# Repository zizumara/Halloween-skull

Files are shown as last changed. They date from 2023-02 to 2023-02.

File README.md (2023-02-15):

# Anamatronic Halloween Skull
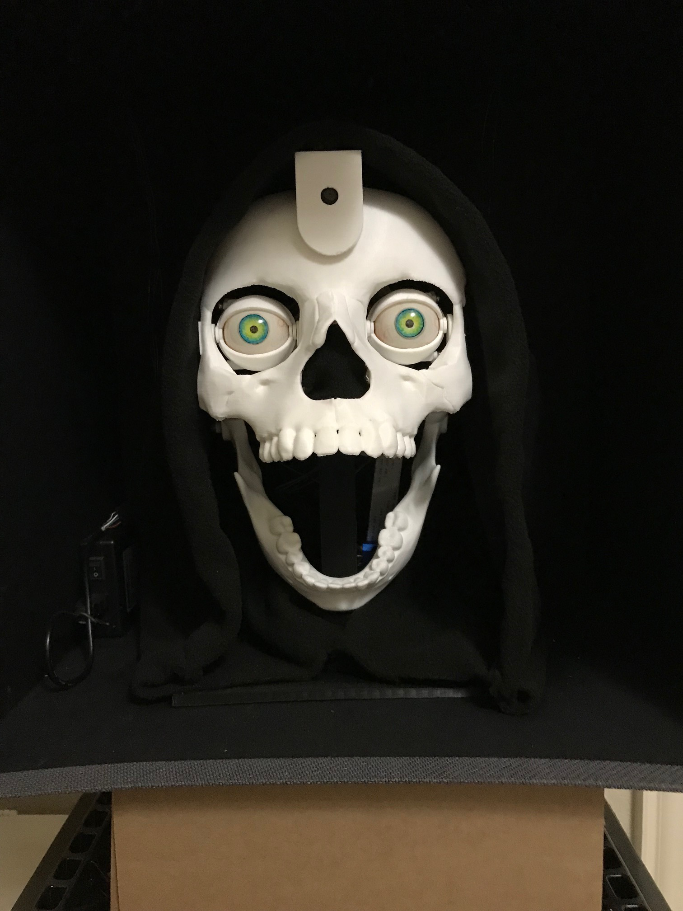
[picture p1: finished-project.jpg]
Finished Project


The eyes in this 3D-printed Halloween project track the movement of faces visible to the Raspberry Pi camera mounted in the forehead.  Eyelid and jaw motions are also controlled with servos to create various expressions (asleep, surprised, talking, etc.) based on the proximity of the person's face.  A small speaker set is attached to the Raspberry Pi to play audio files to go with the expressions.  This is the second of two designs.  In this design, the eyes can be moved independently of each other, whereas the left and right eyelids are limited to moving together.

The eyes are based on this Nilheim Mechatronics project:
http://www.nilheim.co.uk/latest-projects-and-blog/simplified-3d-printed-animatronic-dual-eye-mechanism

The 3D printed skull face was adapted from this Thingiverse project:
https://www.thingiverse.com/thing:4830026

Face detection with Open CV is based on this PyImageSearch tutorial:
https://pyimagesearch.com/2018/02/26/face-detection-with-opencv-and-deep-learning/

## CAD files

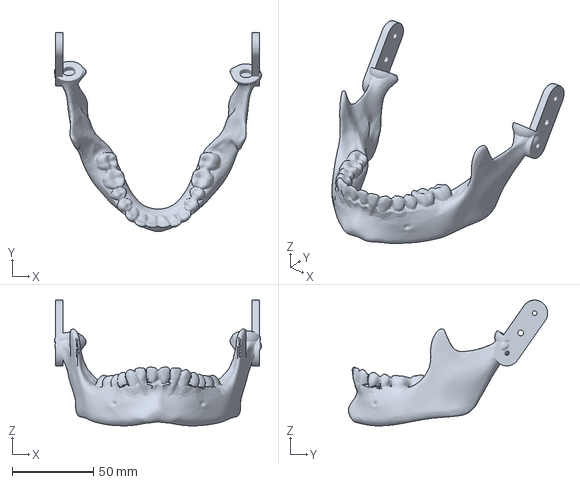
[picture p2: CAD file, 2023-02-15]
3D-printer-files/Mech_Eyes_Mandible.3mf
127.7 x 122.9 x 77.7 mm

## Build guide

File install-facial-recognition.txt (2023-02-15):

1. Update Pi O/S (Buster).
sudo apt-get update
sudo apt-get dist-upgrade

2. Use raspi-config Advanced menu to expand file system and reboot.

3. Install dependencies.
sudo apt-get install build-essential cmake pkg-config
sudo apt-get install libjpeg-dev libtiff5-dev libjasper-dev libpng-dev
sudo apt-get install libavcodec-dev libavformat-dev libswscale-dev libv4l-dev
sudo apt-get install libxvidcore-dev libx264-dev
sudo apt-get install libfontconfig1-dev libcairo2-dev
sudo apt-get install libgdk-pixbuf2.0-dev libpango1.0-dev
sudo apt-get install libgtk2.0-dev libgtk-3-dev
sudo apt-get install libatlas-base-dev gfortran
sudo apt-get install libhdf5-dev libhdf5-serial-dev libhdf5-103
sudo apt-get install libqtgui4 libqtwebkit4 libqt4-test python3-pyqt5
sudo apt-get install python3-dev

4. Create Python virtual environment and install NumPy.
wget https://bootstrap.pypa.io/get-pip.py
sudo python3 get-pip.py
sudo rm -rf ~/.cache/pip
sudo pip install virtualenv virtualenvwrapper
nano ~/.bashrc
Add the following to the end of .bashrc:
  export WORKON_HOME=$HOME/.virtualenvs
  export VIRTUALENVWRAPPER_PYTHON=/usr/bin/python3
  source /usr/local/bin/virtualenvwrapper.sh
Save with CTL-O, ENTER. and then exit with CTL-X.
source ~/.bashrc
mkvirtualenv cv -p python3 --system-site-packages
pip install "picamera[array]"

5. Compile OpenCV from source.
cd ~
wget -O opencv.zip https://github.com/opencv/opencv/archive/4.1.1.zip
wget -O opencv_contrib.zip https://github.com/opencv/opencv_contrib/archive/4.1.1.zip
unzip opencv.zip
unzip opencv_contrib.zip
mv opencv-4.1.1 opencv
mv opencv_contrib-4.1.1 opencv_contrib
sudo nano /etc/dphys-swapfile
Change CONF_SWAPSIZE=100 to CONF_SWAPSIZE=2048.
Save with CTL-O, ENTER. and then exit with CTL-X.
sudo /etc/init.d/dphys-swapfile stop
sudo /etc/init.d/dphys-swapfile start
workon cv
pip install numpy
cd ~/opencv
mkdir build
cd build
cmake -D CMAKE_BUILD_TYPE=RELEASE \
-D CMAKE_INSTALL_PREFIX=/usr/local \
-D OPENCV_EXTRA_MODULES_PATH=~/opencv_contrib/modules \
-D ENABLE_NEON=ON \
-D ENABLE_VFPV3=ON \
-D BUILD_TESTS=OFF \
-D INSTALL_PYTHON_EXAMPLES=OFF \
-D OPENCV_ENABLE_NONFREE=ON \
-D CMAKE_SHARED_LINKER_FLAGS=-latomic \
-D BUILD_EXAMPLES=OFF ..
The following command will compile OpenCV from source.  It may take hours to complete:
make -j4

6. Install OpenCV.
sudo make install
sudo ldconfig

7. Restore swap file size.
sudo nano /etc/dphys-swapfile
Change CONF_SWAPSIZE=2048 to CONF_SWAPSIZE=100.
Save with CTL-O, ENTER. and then exit with CTL-X.
sudo /etc/init.d/dphys-swapfile stop
sudo /etc/init.d/dphys-swapfile start

8. Add sym links to OpenCV (use appropriate latest python3 version; check paths).
cd /usr/local/lib/python3.7/site-packages/cv2/python-3.7
sudo mv cv2.cpython-37m-arm-linux-gnueabihf.so cv2.so
cd ~/.virtualenvs/cv/lib/python3.7/site-packages/
ln -s /usr/local/lib/python3.7/site-packages/cv2/python-3.7/cv2.so cv2.so

9. Test OpenCV installation.
cd ~
workon cv
python
>>> import cv2
>>> cv2.__version__
'4.1.1'
>>>
(use CTL-D to exit python)

10. Install required Python modules.
pip install numpy scipy imutils

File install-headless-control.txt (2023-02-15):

Installation Instructions for Running Headless
(see https://github.com/zizumara/RunHeadless for headless control panel design)

These instructions assume that runheadless.py is located in /home/pi/face-tracker

1. Copy face-tracker.sh to directory /usr/local/bin.

2. Make sure face-tracker.sh is executable with

      sudo chmod 755 /usr/local/bin/face-tracker.sh

3. Copy face-tracker.service to directory /lib/systemd/system.

4. Use the following to enable the service on startup.

      sudo systemctl enable face-tracker

5. To check status after startup, use

      sudo systemctl status face-tracker

6. To stop the service, use

      sudo systemctl stop face-tracker

7. To restart the service, use

      sudo systemctl start face-tracker

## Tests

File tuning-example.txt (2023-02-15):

To perform tuning, run face-tracker.py with -i and -b options to display
video on the desktop and to draw a bounding box around detected faces:
   python3 face-tracker.py -i -b

Note that the following lines in face-tracker.py must be uncommented in order 
to print the bounding box center coordinates on the console.
#            print(f'face at {ratioH:.3f},{ratioV:.3f} '
#                  f'(HL {horizPosL:.1f} VL {vertPosL:.1f} '
#                  f'HR {horizPosR:.1f} VR {vertPosR:.1f} '
#                  f'{mode}); {detectTime:.4f} sec; area {boxArea}')

In a 400x300 pixel frame, the limits of the bounding box centroid are approximately as follows:
   x=35 to 370
   y=35 to 265

This makes the relative position (0.0 - 1.0) of the centroid coordinates (x,y) in the frame to be:
   horiz = (x - 35) / (370 - 35) = (x - 35) / 335
   vert  = 1.0 - (y - 35) / (265 - 35) = 1.0 - (y - 35) / 230
(Note: The vertical ratio flips the y-axis so that 0.0 is at the bottom of the frame.)
(Note: Because the limits are approximations, the values should be cropped to the range 0.0 to 1.0.)

By aligning the eyes to point at the face at each bounding box limit, the limits of the servo
angles are established approximately as follows:
   Left Eye
   channel 2 left: 114 (LL) to 129 (UL) degrees (avg 121)
   channel 2 right: 83 (LR) to 93 (UR) degrees (avg 88)
   channel 0 top: 114 (UL) to 114 (UR) degrees (avg 114)
   channel 0 bottom: 85 (LL) to 91 (LR) degrees (avg 88)
   Right Eye
   channel 6 left: 90 (LL) to 90 (UL) degrees (avg 90)
   channel 6 right: 57 (LR) to 66 (UR) degrees (avg 61)
   channel 4 top: 73 (UL) to 73 (UR) degrees (avg 73)
   channel 4 bottom: 94 (LL) to 97 (LR) degrees (avg 95)
(Note: Left and right are from the perspective of the eyes looking outward.)

The formula for converting centroid coordinates to servo angles is thus:
   channel 0 = 88 + vert * (114 - 88)
   channel 2 = 88 + horiz * (121 - 88)
   channel 4 = 95 - vert * (95 - 73)
   channel 6 = 61 + horiz * (90 - 61)
(Note: The right eye vertical servo moves in the opposite direction as the left eye
vertical servo.)

Set initial servo channel minimum and maximum angles according to the average values,
then tweak the values by moving the face around to see if servo settings correspond to
top, right, left, and bottom limits.

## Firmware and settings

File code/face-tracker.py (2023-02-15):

# face-tracker.py
#
# Track a face in a video stream and output servo controls to point
# a pair of anamatronic eyes at the face.  The eye hardware allows
# each eye to move independently, while the upper lids move in
# unison and the lower lids move in unison.
#
# Controls:
#   l - enter left eye adjustment mode, enabling numeric keypad control
#   r - enter right eye adjustment mode, enabling numeric keypad control
#   t - enter tracking mode, enabling automatic face tracking by both eyes
#   q - quit program and show final tracking positions
#   keypad 1 - capture lower left face detection servo position
#   keypad 3 - capture lower right face detection servo position
#   keypad 7 - capture upper left face detection servo position
#   keypad 9 - capture upper right face detection servo position
#   keypad 2 (down arrow) - adjust eyes down
#   keypad 4 (left arrow) - adjust eyes left
#   keypad 6 (right arrow) - adjust eyes right
#   keypad 8 (up arrow) - adjust eyes up
#

from os import _exit, system, getcwd, path, remove
import addpaths
import pca9685
from imutils.video import VideoStream
import numpy as np
import imutils
import math
import time
import cv2
import subprocess
import argparse
import RPi.GPIO as GPIO

#####################################################################
# CONFIGURATION PARAMETERS
#####################################################################

servoCfgFile = 'servo.conf'
modelFile = 'res10_300x300_ssd_iter_140000.caffemodel'
prototxtFile = 'deploy.prototxt'
screamFile = 'scream1.wav'
laughFile = 'laugh.wav'
biteFile = 'bite.wav'
watchingFile = 'watching.wav'
exitFile = 'exitflag'
CONF_THRESH = 0.5           # confidence threshold for face detection
SERVO_FREQ_HZ = 50
CONTROL_I2C_ADDR = 0x40
MAX_NO_ACTIVITY_TIME = 10

#####################################################################
# GLOBAL CONSTANTS
#####################################################################

# Key assignments (returned by cv2.waitKey)
KEY_LOWER_L  = 177  # keypad 1
KEY_DOWN     = 178  # keypad 2
KEY_LOWER_R  = 179  # keypad 3
KEY_LEFT     = 180  # keypad 4
KEY_CENTER   = 181  # keypad 5
KEY_RIGHT    = 182  # keypad 6
KEY_UPPER_L  = 183  # keypad 7
KEY_UP       = 184  # keypad 8
KEY_UPPER_R  = 185  # keypad 9
KEY_ADJUST   = ord('a')
KEY_ADJUST_R = ord('r')
KEY_ADJUST_L = ord('l')
KEY_TRACK    = ord('t')
KEY_QUIT     = ord('q')

# These are the measured limits of the bounding box centroids and the corresponding
# number of pixels between the limits.
BB_MIN_X = 35
BB_MAX_X = 370
BB_MIN_Y = 35
BB_MAX_Y = 265

BB_WIDTH_X = BB_MAX_X - BB_MIN_X   # width in pixels of area where face can be found
BB_HEIGHT_Y = BB_MAX_Y - BB_MIN_Y  # height in pixels of area where face can be found
BB_AREA_RELAXED = 6000             # size of bounding box to trigger relaxed behavior
BB_AREA_STARTLED = 32000           # size of bounding box to trigger startled behavior


#####################################################################
# CLASSES
#####################################################################

class EyeControl():
    """
    This class abstracts the controller setting of eye positions to be relative
    to the configured range of horizontal and vertical angles of the servos.
    """

    MOVE_UP    = 1
    MOVE_DOWN  = 2
    MOVE_LEFT  = 3
    MOVE_RIGHT = 4

    def __init__(self, controller, leftOrRight):
        self.controller = controller
        self.leftOrRight = leftOrRight
        self.chanH = None
        self.chanV = None
        self.chanAngleH = pca9685.ANGLE_INVALID
        self.chanAngleV = pca9685.ANGLE_INVALID
        self.minAngleH = None
        self.maxAngleH = None
        self.minAngleV = None
        self.maxAngleV = None
        self.degreesH = None
        self.degreesV = None
        # Dictionary of recorded face position locations.
        self.locsDict = { KEY_LOWER_L : (0.0, 0.0),
                          KEY_LOWER_R : (0.0, 0.0),
                          KEY_UPPER_L : (0.0, 0.0),
                          KEY_UPPER_R : (0.0, 0.0),
                        }
        # Marked location key names
        self.recordDict = { KEY_LOWER_L : 'lower L',
                            KEY_LOWER_R : 'lower R',
                            KEY_UPPER_L : 'upper L',
                            KEY_UPPER_R : 'upper R'
                           }



    def setConfig(self):
        """
        Set the channel numbers and angle limits for the eyeball servos from their
        configuration names.
        """
        isValid = False
        if self.leftOrRight == 'left':
            self.chanH = self.controller.getChannel('left-x-axis')
            self.chanV = self.controller.getChannel('left-y-axis')
            (self.minAngleH, self.maxAngleH) = self.controller.getLimits('left-x-axis')
            (self.minAngleV, self.maxAngleV) = self.controller.getLimits('left-y-axis')
        else:
            self.chanH = self.controller.getChannel('right-x-axis')
            self.chanV = self.controller.getChannel('right-y-axis')
            (self.minAngleH, self.maxAngleH) = self.controller.getLimits('right-x-axis')
            (self.minAngleV, self.maxAngleV) = self.controller.getLimits('right-y-axis')
        if (not self.chanH == None and not self.chanV == None and
            not self.minAngleH == None and not self.maxAngleH == None and
            not self.minAngleV == None and not self.maxAngleV == None):
            self.degreesH = self.maxAngleH - self.minAngleH
            self.degreesV = self.maxAngleV - self.minAngleV
            isValid = True
        print(f'{self.leftOrRight} eye servo configuration:')
        print(f'  x-axis chan={self.chanH}, min angle={self.minAngleH}, max angle={self.maxAngleH}')
        print(f'  y-axis chan={self.chanV}, min angle={self.minAngleV}, max angle={self.maxAngleV}')
        return isValid

    def center(self):
        """
        Center the eye horizontally and vertically.
        """
        self.chanAngleH = self.controller.setServoPosition(self.chanH, 'center')
        self.chanAngleV = self.controller.setServoPosition(self.chanV, 'center')

    def adjust(self, direction, change):
        """
        Apply a change in degrees to the horizontal or vertical position of the eyeball.
        """
        angleNewH = pca9685.ANGLE_INVALID
        angleNewV = pca9685.ANGLE_INVALID
        if direction == EyeControl.MOVE_UP:
            if self.leftOrRight == 'right':
                change = -change
            angleNewV = self.controller.setServoAngle(self.chanV, self.chanAngleV + change)
        elif direction == EyeControl.MOVE_DOWN:
            if self.leftOrRight == 'right':
                change = -change
            angleNewV = self.controller.setServoAngle(self.chanV, self.chanAngleV - change)
        elif direction == EyeControl.MOVE_LEFT:
            angleNewH = self.controller.setServoAngle(self.chanH, self.chanAngleH + change)
        elif direction == EyeControl.MOVE_RIGHT:
            angleNewH = self.controller.setServoAngle(self.chanH, self.chanAngleH - change)
        if not angleNewH == pca9685.ANGLE_INVALID:
            self.chanAngleH = angleNewH
        if not angleNewV == pca9685.ANGLE_INVALID:
            self.chanAngleV = angleNewV

    def setRelativePosition(self, ratioHoriz, ratioVert):
        """
        Set the relative horizontal (0 - 1.0) and vertical (0 - 1.0) position of
        the eyeball, where a horizontal ratio of 1.0 is all the way to the left and
        a vertical ratio of 1.0 is all the way up.
        """
        angleNewH = self.minAngleH + (ratioHoriz * self.degreesH)
        if self.leftOrRight == 'left':
            angleNewV = self.minAngleV + (ratioVert * self.degreesV)
        else:
            angleNewV = self.maxAngleV - (ratioVert * self.degreesV)
        angleNewH = self.controller.setServoAngle(self.chanH, angleNewH)
        angleNewV = self.controller.setServoAngle(self.chanV, angleNewV)
        if not angleNewH == pca9685.ANGLE_INVALID:
            self.chanAngleH = angleNewH
        if not angleNewV == pca9685.ANGLE_INVALID:
            self.chanAngleV = angleNewV

    def getCurrentPosition(self):
        """
        Return current horizontal and vertical eyeball servo positions in degrees.
        """
        return (self.chanAngleH, self.chanAngleV)

    def markLocation(self, cmdKey):
        self.locsDict[cmdKey] = (self.chanAngleH, self.chanAngleV)
        print(f'Captured {self.recordDict[cmdKey]} position at {self.locsDict[cmdKey]}.')


class ExpressionControl():
    """
    This class abstracts the controller setting of eyelid positions, jaw position, and
    audio effects as behaviors.
    """

    ASLEEP = 1
    RELAXED = 2
    STARTLED = 3
    SUSPICIOUS = 4
    LAUGHING = 5
    WIDEEYED = 6
    BITING = 7

    def __init__(self, controller):
        self.controller = controller
        self.chLidUpper = None
        self.chLidLower = None
        self.chJaw = None
        self.current = None

    def get(self):
        return self.current

    def config(self):
        """
        Set the channel numbers for each servo from their configuration names.
        """
        self.chLidUpper = self.controller.getChannel('upper-lids')
        self.chLidLower = self.controller.getChannel('lower-lids')
        self.chJaw       = self.controller.getChannel('jaw')
        isValid = (not self.chLidUpper == None and
                   not self.chLidLower == None
                   and not self.chJaw == None)
        print('Configure channels:')
        print(f'  upper-lids={self.chLidUpper}')
        print(f'  lower-lids={self.chLidLower}')
        print(f'  jaw={self.chJaw}')
        return isValid

    def setAsleep(self):
        self.current = ExpressionControl.ASLEEP
        self.controller.setServoPosition(self.chLidUpper, 'closed')
        self.controller.setServoPosition(self.chLidLower, 'closed')
        self.controller.setServoPosition(self.chJaw, 'closed')

    def setRelaxed(self):
        self.current = ExpressionControl.RELAXED
        self.controller.setServoPosition(self.chLidUpper, 'halfopen')
        self.controller.setServoPosition(self.chLidLower, 'halfopen')
        self.controller.setServoPosition(self.chJaw, 'closed')

    def setWideEyed(self):
        self.current = ExpressionControl.WIDEEYED
        self.controller.setServoPosition(self.chLidUpper, 'open')
        self.controller.setServoPosition(self.chLidLower, 'open')
        self.controller.setServoPosition(self.chJaw, 'closed')

    def setStartled(self, soundFile):
        self.current = ExpressionControl.STARTLED
        soundProc = subprocess.Popen(['aplay', '-Dhw:0,0', soundFile])
        returnCode = soundProc.poll()
        if returnCode != None:
            print(f'ERROR: Launch of aplay failed with return code {returnCode}.')
        self.controller.setServoPosition(self.chLidUpper, 'open')
        self.controller.setServoPosition(self.chLidLower, 'open')
        self.controller.setServoPosition(self.chJaw, 'open')

    def setSuspicious(self, fraction):
        self.current = ExpressionControl.SUSPICIOUS
        self.controller.setServoPositionRel(self.chLidUpper, 'halfopen', 'closed', fraction)
        self.controller.setServoPositionRel(self.chLidLower, 'halfopen', 'closed', fraction)
        self.controller.setServoPosition(self.chJaw, 'closed')

    def setLaughing(self, soundFile):
        self.current = ExpressionControl.LAUGHING
        soundProc = subprocess.Popen(['aplay', '-Dhw:0,0', soundFile])
        returnCode = soundProc.poll()
        if returnCode != None:
            print(f'ERROR: Launch of aplay failed with return code {returnCode}.')
        for i in range(0,6):
            self.controller.setServoPositionRel(self.chJaw, 'closed', 'open', 0.2)
            time.sleep(0.1)
            self.controller.setServoPosition(self.chJaw, 'closed')
            time.sleep(0.1)

    def setWatching(self, soundFile):
        self.current = ExpressionControl.LAUGHING
        soundProc = subprocess.Popen(['aplay', '-Dhw:0,0', soundFile])
        returnCode = soundProc.poll()
        if returnCode != None:
            print(f'ERROR: Launch of aplay failed with return code {returnCode}.')
        self.controller.setServoPosition(self.chLidUpper, 'open')
        self.controller.setServoPosition(self.chLidLower, 'open')
        # we're
        self.controller.setServoPositionRel(self.chJaw, 'closed', 'open', 0.3)
        time.sleep(0.8)
        self.controller.setServoPosition(self.chJaw, 'closed')
        time.sleep(0.15)
        # watch-
        self.controller.setServoPositionRel(self.chJaw, 'closed', 'open', 0.5)
        time.sleep(0.2)
        self.controller.setServoPosition(self.chJaw, 'closed')
        time.sleep(0.1)
        # -ing
        self.controller.setServoPositionRel(self.chJaw, 'closed', 'open', 0.3)
        time.sleep(0.2)
        self.controller.setServoPosition(self.chJaw, 'closed')
        time.sleep(0.1)
        # you
        self.controller.setServoPositionRel(self.chJaw, 'closed', 'open', 0.5)
        time.sleep(0.8)
        self.controller.setServoPosition(self.chJaw, 'closed')
        time.sleep(0.1)

    def setBiting(self, soundFile):
        self.current = ExpressionControl.BITING
        soundProc = subprocess.Popen(['aplay', '-Dhw:0,0', soundFile])
        returnCode = soundProc.poll()
        if returnCode != None:
            print(f'ERROR: Launch of aplay failed with return code {returnCode}.')
        self.controller.setServoPosition(self.chLidUpper, 'open')
        self.controller.setServoPosition(self.chLidLower, 'open')
        self.controller.setServoPositionRel(self.chJaw, 'closed', 'open', 0.4)
        time.sleep(0.1)
        self.controller.setServoPosition(self.chJaw, 'closed')
        time.sleep(0.1)


class Lighting():
    """
    This class encapsulates the GPIO outputs used to turn lighting on and off.
    """

    PIN_LIGHT1 = 13
    PIN_LIGHT2 = 15
    PIN_LIGHT3 = 16

    def __init__(self):
        GPIO.setmode(GPIO.BOARD)
        GPIO.setwarnings(False)
        GPIO.setup(Lighting.PIN_LIGHT1, GPIO.OUT)
        GPIO.setup(Lighting.PIN_LIGHT2, GPIO.OUT)
        GPIO.setup(Lighting.PIN_LIGHT3, GPIO.OUT)

    def on(self):
        GPIO.output(Lighting.PIN_LIGHT1, GPIO.HIGH)
        GPIO.output(Lighting.PIN_LIGHT2, GPIO.HIGH)
        GPIO.output(Lighting.PIN_LIGHT3, GPIO.HIGH)

    def off(self):
        GPIO.output(Lighting.PIN_LIGHT1, GPIO.LOW)
        GPIO.output(Lighting.PIN_LIGHT2, GPIO.LOW)
        GPIO.output(Lighting.PIN_LIGHT3, GPIO.LOW)


#####################################################################
# MAIN
#####################################################################

parser = argparse.ArgumentParser()
parser.add_argument('-i', '--display', required=False, action='store_true',
                    help='display video')
parser.add_argument('-b', '--box', required=False, action='store_true',
                    help='draw box around face')
args = vars(parser.parse_args())
showImage = False           # display captured frame when True
drawBox = False             # draw box around detected face when True
if args['display'] == True:
    showImage = True
if args['box'] == True:
    drawBox = True

exitPath = path.join(getcwd(), exitFile)

# Adjust key names
adjustDict = {KEY_DOWN   : 'down',
              KEY_LEFT   : 'left',
              KEY_CENTER : 'center',
              KEY_RIGHT  : 'right',
              KEY_UP     : 'up'
             }

# Mode key names
modeDict = {KEY_TRACK  : 'track',
            KEY_ADJUST : 'adjust',
            KEY_ADJUST_R: 'adjust right',
            KEY_ADJUST_L: 'adjust left'
           }

# Initialize the servo controller and load its configuration.
print('Initializing servo controller...')
controller = pca9685.PCA9685Controller(CONTROL_I2C_ADDR)
controlReady = controller.loadConfig(servoCfgFile)
if not controlReady:
    print('ERROR: Unable to load controller configuration.  Quitting.')
    _exit(1)
controller.start(SERVO_FREQ_HZ)
controller.printStatus()

# Create and initialize the eye and expression control objects.  Note that the
# min/max horizontal/vertical angle limits of the eye servos are determined
# empirically by adjusting the eye positions so that they appear to point at
# a face detected at each edge of the frame.
expression = ExpressionControl(controller)
isExpCfgValid = expression.config()
if not isExpCfgValid:
    print('ERROR: Configuration of ExpressionControl failed.  Quitting.')
    _exit(1)
expression.setAsleep()
isStartleArmed = True
eyeL = EyeControl(controller, 'left')
eyeR = EyeControl(controller, 'right')
isEyeCfgValid = eyeL.setConfig() and eyeR.setConfig()
if not isEyeCfgValid:
    print('ERROR: Configuration of EyeControl failed.  Quitting.')
    _exit(1)
eyeL.center()
eyeR.center()
activeEye = eyeL
mode = modeDict[KEY_TRACK]

# Create the lighting control and turn on the lights.
lights = Lighting()
lights.on()

# Load the serialized model from disk.
print('Loading model...')
net = cv2.dnn.readNetFromCaffe(prototxtFile, modelFile)

# Use the Raspberry Pi hardware for the inference engine.
net.setPreferableBackend(cv2.dnn.DNN_BACKEND_OPENCV)
net.setPreferableTarget(cv2.dnn.DNN_TARGET_CPU)

# Initialize the video stream and allow the camera sensor to warm up.
print('Starting video stream...')
vs = VideoStream(usePiCamera=True).start()
time.sleep(2.0)
print(f'Initialization complete, entering {mode} mode.')
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
